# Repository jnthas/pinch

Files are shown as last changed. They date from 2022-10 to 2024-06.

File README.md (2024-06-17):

# Pinch: a password storage for nerds

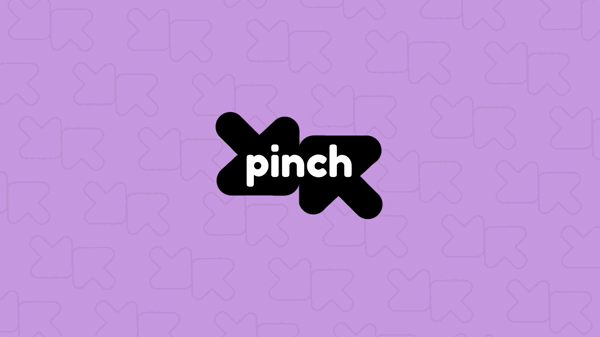
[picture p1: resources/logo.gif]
Pinch Logo


## Featuring video
Featuring Pinch video (https://www.youtube.com/watch?v=X7CdZzqYkFY)

## What is Pinch?

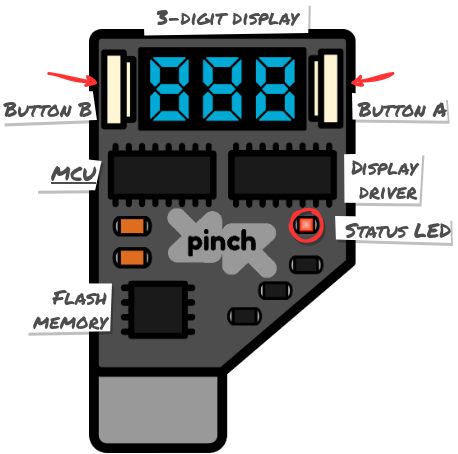
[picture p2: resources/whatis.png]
What is Pinch?


Pinch is an open-source, personal and portable device capable of storing, retrieving and entering your passwords on demand. It is a physical device with no internet access and only works through manual activation.
Pinch is the size of a USB flash drive. It has a USB interface, two buttons and a three digit display which are used to select and confirm the desired password. When confirming, simply put the focus on the password field and the Pinch will enter it for you.

## How does Pinch work?

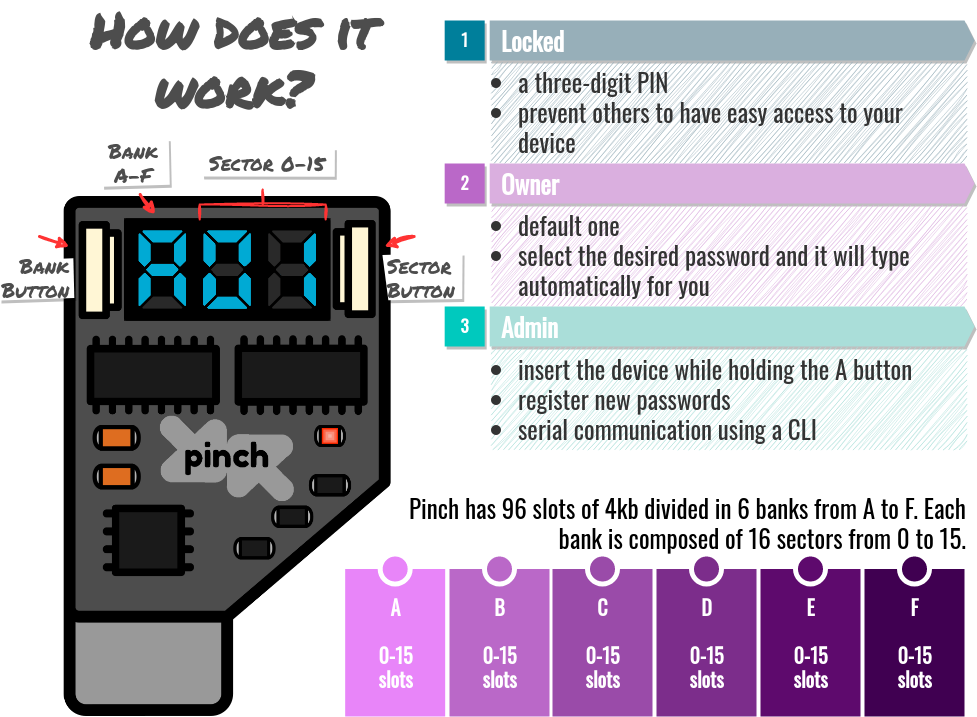
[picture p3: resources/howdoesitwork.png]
How does it work?


Pinch has three modes of operation
- The first state is when your device is locked. To start using it, you need to enter a three-digit PIN, this will prevent others who have easy access to your device.
- The second is the default one, the Owner Mode where Pinch acts like a keyboard. When you plug it into the computer, it can enter passwords as if it were you without anyone seeing it.
- The third one, is the Admin Mode. In this mode you can register new passwords, set parameters and list existing labels via serial communication using a CLI. For security reasons, you cannot retrieve passwords in this mode, only register them. Select the desired slot on the device and enter the label and password on the command line. Disconnect and connect again and the password is now available.

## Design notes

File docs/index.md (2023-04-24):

<div style="text-align: center">
<iframe width="560" height="315" src="https://www.youtube.com/embed/X7CdZzqYkFY" title="Pinch promo video" frameborder="0" allow="accelerometer; autoplay; clipboard-write; encrypted-media; gyroscope; picture-in-picture; web-share" allowfullscreen></iframe>
</div>

Pinch is an open-source, personal and portable device capable of storing, retrieving and entering your passwords on demand. It is a physical device with no internet access and only works through manual activation.
Pinch is the size of a USB flash drive. It has a USB interface, two buttons and a three digit display which are used to select and confirm the desired password. When confirming, simply put the focus on the password field and the Pinch will enter it for you.

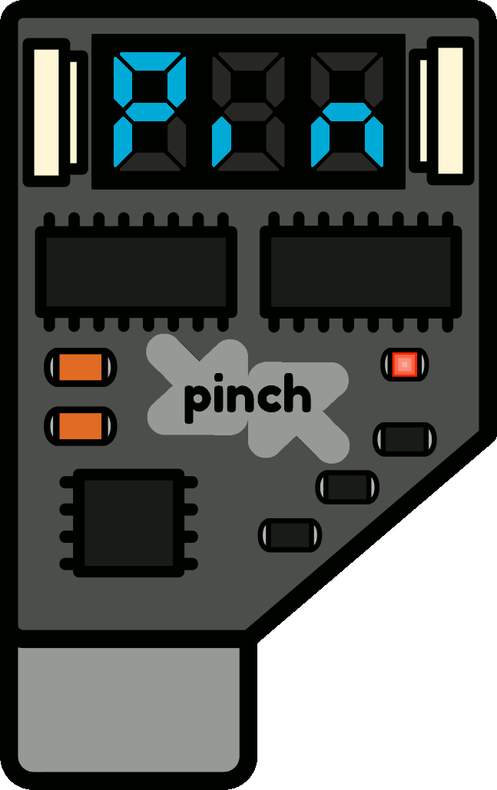
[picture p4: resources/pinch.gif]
Pinch Animation


## How does Pinch work?
Pinch has three modes of operation
- The first is when your device is locked. To start using it, you need to enter a three-digit PIN, this will prevent others who have access to your device from easily retrieving your passwords.
- The second is the default one, the keyboard mode. When you plug it into the computer, it is able to enter passwords as if it were you without anyone seeing.
- The third, is the CDC. In this mode you can register new passwords and list existing labels via serial communication using a CLI. For security reasons, you cannot retrieve passwords in this mode, only register them. Select the desired slot on the device and enter the label and password on the command line. Disconnect and connect again and the password is now available.

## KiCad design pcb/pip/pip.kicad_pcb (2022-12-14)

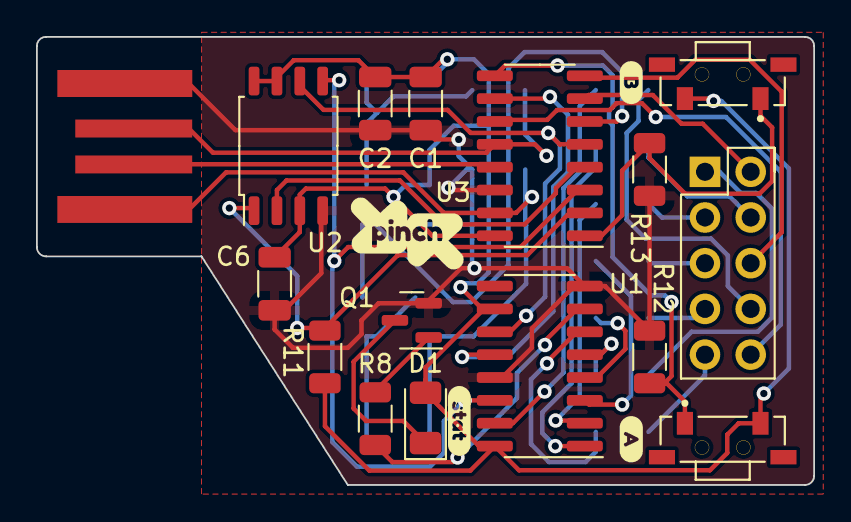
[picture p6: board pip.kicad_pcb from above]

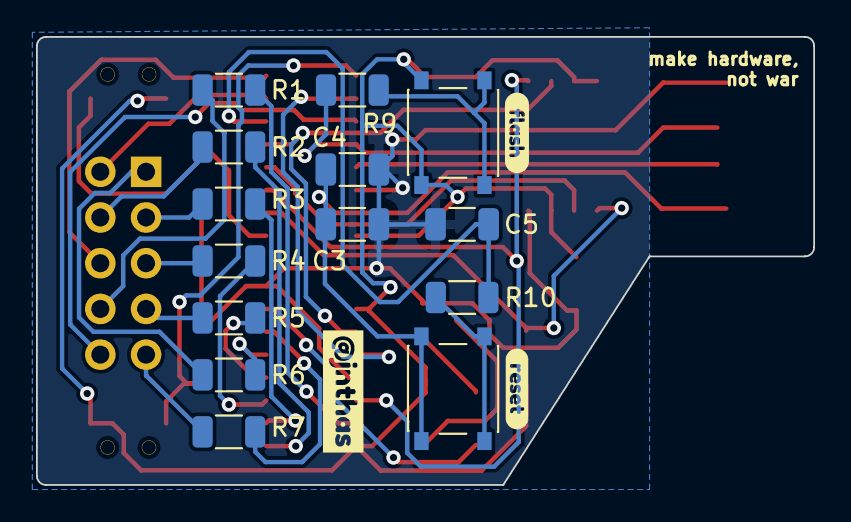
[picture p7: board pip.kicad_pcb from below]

Board: 2 copper layers, 43.2 x 24.9 mm, 36 parts (17 on the bottom side), 35 nets.

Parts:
C1, C2, C3, C5, C6: 0.1uF; C_1206_3216Metric
C4: 4.7uF; C_1206_3216Metric
D1: LED; LED_1206_3216Metric
DS1: NET-2531AB-11; Display_2531AB
J1: USBPCB; USB-A-PCB
Q1: BC847; SOT-23
R1, R2, R3, R4, R5, R6, R7, R8: 1K; R_1206_3216Metric
R9, R12, R13: 10K; R_1206_3216Metric
R10: 330R; R_1206_3216Metric
R11: 4.7K; R_1206_3216Metric
SW1: FLASH; SW_Push_45x45mm_H1.5mm
SW2: RESET; SW_Push_45x45mm_H1.5mm
SW3: BUTTON_A; SW_TL3330AF130QG
SW4: BUTTON_B; SW_TL3330AF130QG
U1: 74HC595; SOP-16_3.9x9.9mm_P1.27mm
U2: W25Q32JVSS; SOIC-8_5.23x5.23mm_P1.27mm
U3: CH552G; SOP-16_3.9x9.9mm_P1.27mm
kibuzzard-63727E71: G***; kibuzzard-63727E71
kibuzzard-63727E80: G***; kibuzzard-63727E80
kibuzzard-63728AEE: G***; kibuzzard-63728AEE
kibuzzard-63728AF8: G***; kibuzzard-63728AF8
kibuzzard-63728B2A: G***; kibuzzard-63728B2A
kibuzzard-63728C1B: G***; kibuzzard-63728C1B

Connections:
GND: C1.2, C2.2, C3.2, C4.2, C5.2, C6.1, J1.GND, Q1.2 (E), R12.1, R13.1, U1.8 (GND), U1.13 (~OE), U2.4 (GND), U3.14 (GND)
unnamed: D1.1 (K), Q1.3 (C)
unnamed: DS1.1 (f), R6.2
unnamed: DS1.2 (c), R3.2
unnamed: DS1.3 (d), R4.2
unnamed: DS1.4 (e), R5.2
unnamed: DS1.5 (g), R7.2
unnamed: DS1.7 (a), R1.2
unnamed: DS1.9 (b), R2.2
unnamed: Q1.1 (B), R8.2
unnamed: R1.1, U1.15 (QA)
unnamed: R2.1, U1.1 (QB)
unnamed: R3.1, U1.2 (QC)
unnamed: R4.1, U1.3 (QD)
unnamed: R5.1, U1.4 (QE)
unnamed: R6.1, U1.5 (QF)
unnamed: R7.1, U1.6 (QG)
unnamed: R8.1, U1.7 (QH)
unnamed: R9.2, SW1.1 (A), SW1.2 (A)
unnamed: R10.2, SW2.1 (A), SW2.2 (A)
P1.1: R12.2, SW3.1 (A), U3.9 (P1.1)
P1.4: R11.2, U2.1 (~CS), U3.2 (P1.4)
P1.5: U1.14 (SER), U2.5 (DI(IO0)), U3.3 (P1.5/MOSI)
P1.6: U2.2 (DO(IO1)), U3.4 (P1.6/MISO)
P1.7: U1.11 (SRCLK), U2.6 (CLK), U3.5 (P1.7/SCK)
P3.0: DS1.8 (CA_D2), U3.8 (P3.0/RXD)
P3.1: DS1.10 (CA_D1), U3.7 (P3.1/TXD)
P3.2: R13.2, SW4.1 (A), U3.1 (P3.2)
P3.3: U1.12 (RCLK), U3.10 (P3.3)
P3.4: DS1.6 (CA_D3), U3.11 (P3.4)
P3.6: J1.USB_DP (D+), R9.1, U3.12 (UD+/P3.6)
P3.7: J1.USB_DC (D-), U3.13 (UD-/P3.7)
RESET: C5.1, R10.1, U3.6 (RST)
VBUS: C3.1, C4.1, J1.5V (VBUS), SW2.3 (B), SW2.4 (B), U3.15 (VCC)
VCC: C1.1, C2.1, C6.2, D1.2 (A), R11.1, SW1.3 (B), SW1.4 (B), SW3.3 (B), SW4.3 (B), U1.10 (~SRCLR), U1.16 (VCC), U2.3 (IO2), U2.7 (IO3), U2.8 (VCC), U3.16 (3V3)

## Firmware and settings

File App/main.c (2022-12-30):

#include <stdlib.h>
#include <stdbool.h>
#include <string.h>
#include <math.h>
#include <stdint.h>
#include <stdio.h>
#include "ch552.h"
#include "debug.h"
#include "core/Print.h"
#include "core/GPIO.h"
#include "core/USBHandler.h"
#include "core/hid/USBHIDKeyboard.h"
#include "core/cdc/USBCDC.h"
#include "components/sevenSegmentDisplay.h"
#include "components/inputButton.h"
#include "app/pinch.h"
#include "app/serialcom.h"
#include "app/locker.h"


/*
Pinch has 96 slots of 4kb divided in 6 banks from A to F. Each bank is composed of 16 sectors from 0 to 15


Premisses:
  - You can't recover a password in CDC mode
  - You must confirm manually when replacing a slot 
  - All operations should have a manually operation
  - There will be a flag indicating if the device must be destroyed in case user removes device before it happens
  - At first, device is empty and it will accept a special command to set parameters like pin code, after that only if you destroy all data and restart the device  
  - To set pin code it must be confirmed manually before


TODO List:

- Implement self-destroy after 3 attempts of pin code
- List all labels in CDC mode, too check what is available
- Create a webpage to list all slots (webserial)
- Create a CLI tool to handle operations in CDC mode
- Create a parameter section in flash and save : pin code, analog button threashold, self-destroy enabled, # attempts self-destroy
- Turn on led when a slot is used 
- Implement LED function: 
  - Locked: always on
  - CDC MOde: Blink every 3 secs + turned on when navigate in a used slot
  - KBD MOde: Off by default + turned on when navigate in a used slot
- Create a 1-sec startup screen - KBD or CDC 
- Encrypt passwords 
- Always reduce the size of firmware!

- Write README
- Record a 1min explaining video
- Write a post
*/



void DeviceUSBInterrupt(void) __interrupt(INT_NO_USB) // USB interrupt service
{
  USBHandler_usbInterrupt();
}

__xdata uint8_t displayPos = 0;
__xdata unsigned long currentMillis = 0;


enum PinchState
{
  Locked,
  CDCMode,
  HIDMode
} pinch_state;


void setup()
{
  CfgFsys();
  mDelaymS(10);

  Button_setup();

  uint8_t currentButtonState = Button_startupCheck();
  if (currentButtonState == BUTTON_A_PRESSED) {
    // CDC Mode
    USBSerial_setup();
    USBSerial();
    SerialCom_setup();

    pinch_state = CDCMode;
  } else {
    // KBD Mode (Default)
    Keyboard_setup();
    pinch_state = HIDMode;
  }
  
  SPISetup();

  Display_setup();
  
  Pinch_setup();
  Locker_setup();
}


void loop()
{
 
  switch (pinch_state) 
  {
    case Locked:
      if (Locker_loop(currentMillis))
        pinch_state = CDCMode;
      break;

    case CDCMode:
      Pinch_loopCDC(currentMillis);
      break;
    
    case HIDMode:
      Pinch_loopHID(currentMillis);
      break;
  }

  Display_update();
}

void main()
{

  setup();

  while (1)
  {
    loop();
  
    currentMillis+=4;
  }
 
}

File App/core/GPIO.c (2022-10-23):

#include "GPIO.h"

void p1Mode(__xdata uint8_t portBit, __xdata uint8_t mode)
{

  if (mode == INPUT)
  {
    P1_MOD_OC &= ~(1 << portBit);
    P1_DIR_PU &= ~(1 << portBit);
  }
  else if (mode == INPUT_PULLUP)
  {
    P1_MOD_OC |= (1 << portBit);
    P1_DIR_PU |= (1 << portBit);
  }
  else if (mode == OUTPUT)
  {
    P1_MOD_OC &= ~(1 << portBit);
    P1_DIR_PU |= (1 << portBit);
  }
  else if (mode == OUTPUT_OD)
  {
    P1_MOD_OC |= (1 << portBit);
    P1_DIR_PU &= ~(1 << portBit);
  }
}

void p3Mode(__xdata uint8_t portBit, __xdata uint8_t mode)
{
  if (mode == INPUT)
  {

    P3_MOD_OC &= ~(1 << portBit);
    P3_DIR_PU &= ~(1 << portBit);
  }
  else if (mode == INPUT_PULLUP)
  {

    P3_MOD_OC |= (1 << portBit);
    P3_DIR_PU |= (1 << portBit);
  }
  else if (mode == OUTPUT)
  {

    P3_MOD_OC &= ~(1 << portBit);
    P3_DIR_PU |= (1 << portBit);
  }
  else if (mode == OUTPUT_OD)
  {

    P3_MOD_OC |= (1 << portBit);
    P3_DIR_PU &= ~(1 << portBit);
  }
}

static void turnOffPWM(__xdata uint8_t pwm)
{
  switch (pwm)
  {
  case PIN_PWM1:
    if ((PIN_FUNC & bPWM1_PIN_X) == 0)
    {
      PWM_CTRL &= ~bPWM1_OUT_EN;
    }
    break;
  case PIN_PWM2:
    if ((PIN_FUNC & bPWM2_PIN_X) == 0)
    {
      PWM_CTRL &= ~bPWM2_OUT_EN;
    }
    break;
  case PIN_PWM1_:
    if ((PIN_FUNC & bPWM1_PIN_X) != 0)
    {
      PWM_CTRL &= ~bPWM1_OUT_EN;
    }
    break;
  case PIN_PWM2_:
    if ((PIN_FUNC & bPWM2_PIN_X) != 0)
    {
      PWM_CTRL &= ~bPWM2_OUT_EN;
    }
    break;
  }
}

uint8_t isPinPWM(__xdata uint8_t port, __xdata uint8_t portBit)
{

  if (port == 1 && portBit == 5)
  {
    return PIN_PWM1;
  }
  else if (port == 3)
  {
    if (portBit == 0)
      return PIN_PWM1_;
    else if (portBit == 1)
      return PIN_PWM2_;
    else if (portBit == 4)
      return PIN_PWM2;
  }

  return NOT_ON_PWM;
}

uint8_t digitalRead(__xdata uint8_t pin)
{
  uint8_t portNumber = (pin - (pin % 10)) / 10;
  uint8_t portBit = (pin % 10);
  uint8_t pwm = isPinPWM(portNumber, portBit);

  // If the pin that support PWM output, we need to turn it off
  // before getting a digital reading.
  if (pwm != NOT_ON_PWM)
    turnOffPWM(pwm);

  uint8_t portBuf = 0;

  switch (portNumber)
  {
  case 1:
    portBuf = P1;
    break;
  case 2:
    portBuf = P2;
    break;
  case 3:
    portBuf = P3;
    break;
  default:
    break;
  }

  if (portBuf & portBit)
    return HIGH;
  return LOW;
}

void digitalWrite(__xdata uint8_t pin, __xdata uint8_t val)
{
  uint8_t portNumber = (pin - (pin % 10)) / 10;
  uint8_t portBit = (pin % 10);
  uint8_t pwm = isPinPWM(portNumber, portBit);

  // If the pin that support PWM output, we need to turn it off
  // before doing a digital write.
  if (pwm != NOT_ON_PWM)
    turnOffPWM(pwm);

  // C pointers cannot be used to access the 8051's SFRs (special function registers).

  uint8_t interruptOn = EA;
  EA = 0;

  switch (portNumber)
  {
  case 1:
    if (val == LOW)
    {
      P1 &= ~(1 << portBit);
    }
    else
    {
      P1 |= (1 << portBit);
    }
    break;
  case 2:
    if (val == LOW)
    {
      P2 &= ~(1 << portBit);
    }
    else
    {
      P2 |= (1 << portBit);
    }
    break;
  case 3:
    if (val == LOW)
    {
      P3 &= ~(1 << portBit);
    }
    else
    {
      P3 |= (1 << portBit);
    }
    break;

  default:
    break;
  }

  if (interruptOn)
    EA = 1;
}

uint8_t analogRead(__xdata uint8_t pin)
{
  // ADC pins
  // AIN0 (P1.1)
  // AIN1 (P1.4)
  // AIN2 (P1.5)
  // AIN3 (P3.2)

  uint8_t pinNum;

  if (pin == 11)
    pinNum = 0;
  else if (pin == 14)
    pinNum = 1;
  else if (pin == 15)
    pinNum = 2;
  else if (pin == 32)
    pinNum = 3;
  else
    return 0;

  ADC_CFG = bADC_EN | bADC_CLK;

  ADC_CTRL = (ADC_CTRL & ~(0x03)) | (0x03 & pinNum);

  ADC_START = 1;

  while (ADC_START)
    ;

  return ADC_DATA;
}
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

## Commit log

2022-10-04 fix CDC communication error
    [main.c]
2022-10-16 display and buttons integration
2022-10-22 displays current slot
2022-10-23 refactoring buttons and get mem address
2022-11-02 pcb layout
    [pip.kicad_pcb, pip.kicad_sch]
2022-11-15 pcb design
    [pip-backup.kicad_pcb, pip.dsn, pip.kicad_pcb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]
2022-11-19 small fixes
    [pip.kicad_pcb]
2022-11-19 add pinch logo
    [pip.kicad_pcb]
2022-12-26 create multi device
2022-12-28 multi usb device 1
2022-12-29 multi device part 2
2022-12-29 multi device part 3
2022-12-29 refactoring multi device
2022-12-30 multi device working
